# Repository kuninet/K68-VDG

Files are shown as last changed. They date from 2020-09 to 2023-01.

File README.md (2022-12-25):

# SBC6800/6809/6303用 VDGビデオボード

# ★★REV1.1 既知のバグ:  ☆☆
ガーバーデータに誤りがあり、2SC1815と2SC1015のシルク印刷が逆転しています。Q1、Q2の部品番号シルクが正しいです。

## 概要
- SBC68系バスにつながるMC6847 VDG LSIを使用したビデオボードです。
  - REV1基板はアドレスデコードラインにバグがあります。REV2で改善します。プリント基板をお使いの場合は、パターンカット、ジャンパが必要です

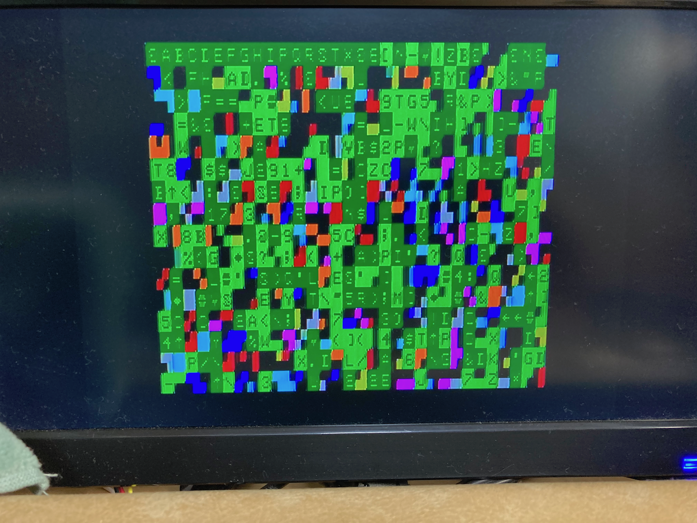
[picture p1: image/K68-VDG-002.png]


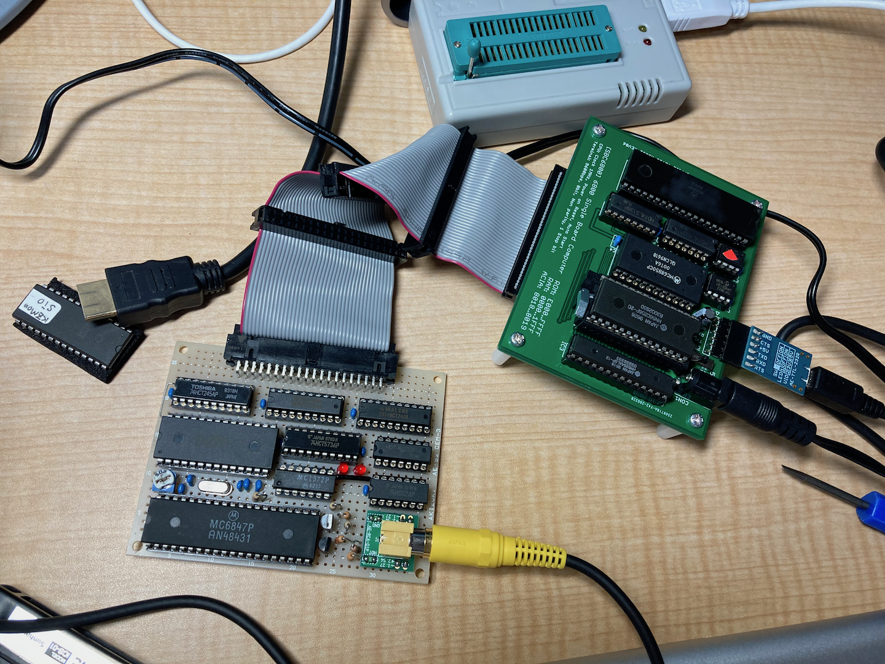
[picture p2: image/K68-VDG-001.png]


## メモリーマップ
- 本基板はVRAMとして8kBのメモリー領域と、VDG設定用レジスタがメモリーマップドI/Oとしてメモリーを占有します。
- 本基板はTomi9さん作のSBC I/O( https://sbc738827564.wordpress.com/2018/08/11/sbc-io-rev02/ )と共存できることを目指しています。

|メモリーアドレス|用途|
|:---|:---|
|$8110|VDG設定用レジスタ|
|\$A000-\$BFFF または \$C000-\$DFFF|ビデオRAM|

## SBC68系バス
- Tomi9さん作のSBC I/O ( https://sbc738827564.wordpress.com/2018/08/11/sbc-io-rev02/ ) に準拠しています。SBC6303ルーズキットとは若干信号線が異なりますのでご注意ください。(ジャンパを実施すれば使えます)

## ディレクトリ構造
|ディレクトリ|用途|
|:---|:---|
|KiCAD/|KiCAD用データ|
|image/|回路図等イメージデータ|

## ライセンス
- MITライセンスで公開します。

## Special Thanks
- 本基板は先人のみなさまの情報で作成することができました。
- pmig96さん・・・MC6847テストサーキット
  - https://pmig96.wordpress.com/2020/07/24/mc6847-test-circuit-part-3/
- Tomi9さん・・・SBC I/Oボード
  - https://sbc738827564.wordpress.com/2018/08/11/sbc-io-rev02/

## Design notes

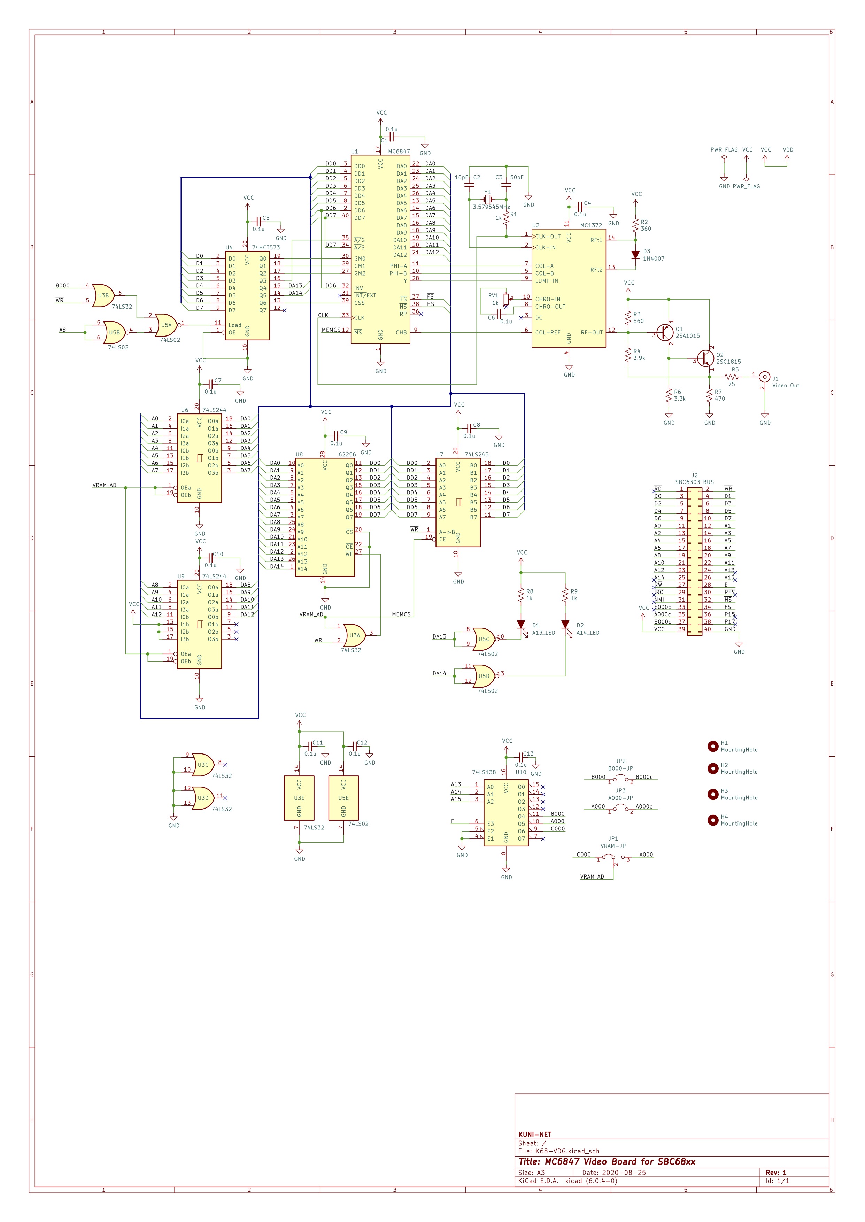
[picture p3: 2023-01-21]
image/K68-VDG.jpg

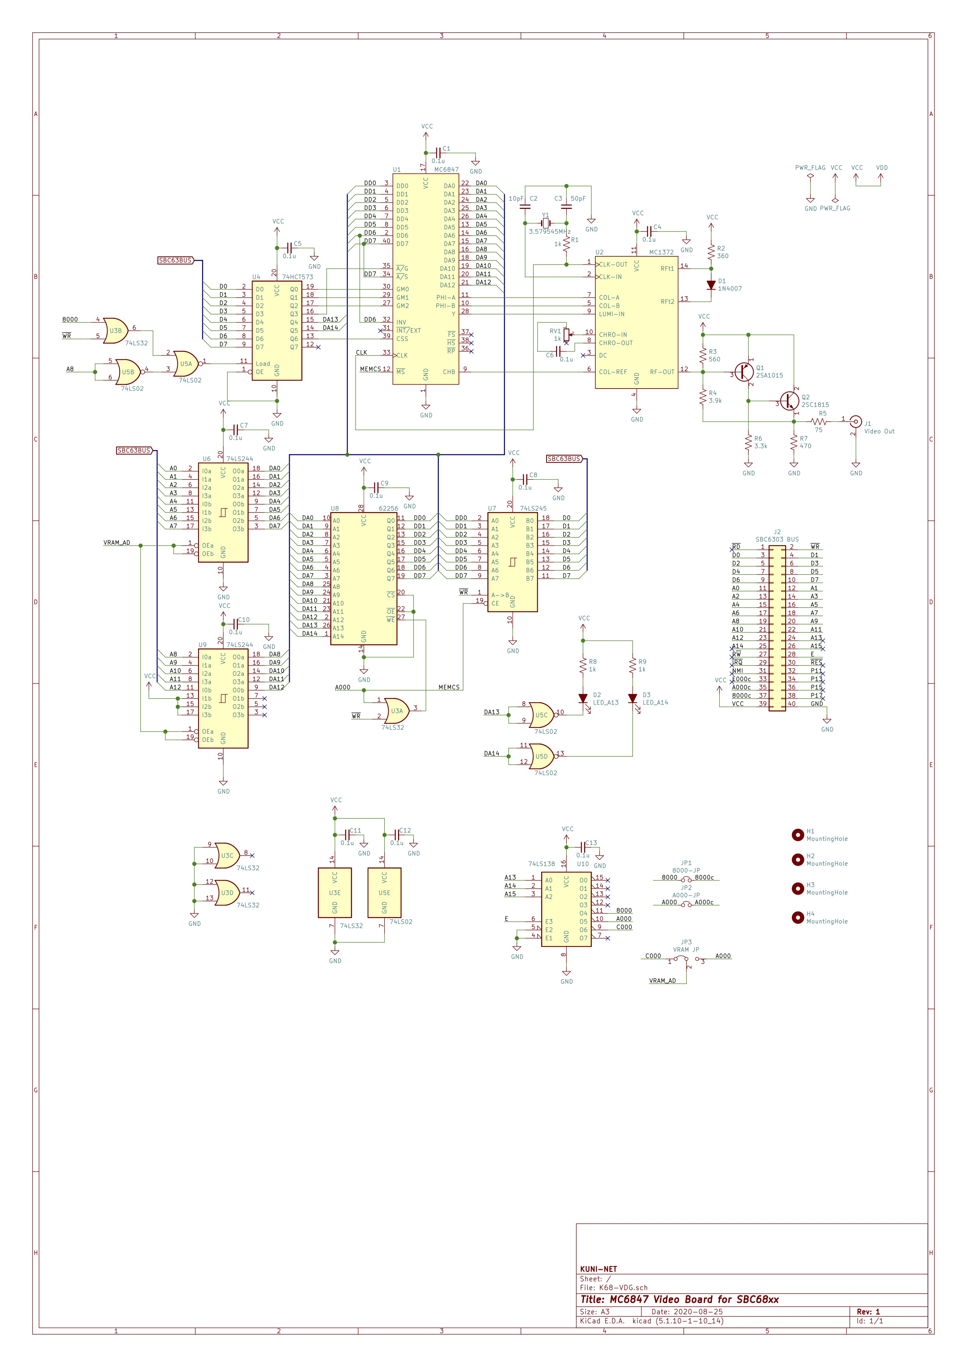
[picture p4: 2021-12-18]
image/K68-VDG-REV1.jpg

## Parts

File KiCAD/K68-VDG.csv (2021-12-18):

Reference | Value | Footprint | Datasheet
J2 | SBC6303 BUS | Connector_PinHeader_2.54mm:PinHeader_2x20_P2.54mm_Horizontal | ~
C1 | 0.1u | Capacitor_THT:C_Disc_D3.0mm_W1.6mm_P2.50mm | ~
C2 | 10pF | Capacitor_THT:C_Disc_D3.0mm_W1.6mm_P2.50mm | ~
C3 | 50pF | Capacitor_THT:C_Disc_D3.0mm_W1.6mm_P2.50mm | ~
C4 | 0.1u | Capacitor_THT:C_Disc_D3.0mm_W1.6mm_P2.50mm | ~
C5 | 0.1u | Capacitor_THT:C_Disc_D3.0mm_W1.6mm_P2.50mm | ~
C6 | 0.1u | Capacitor_THT:C_Disc_D3.0mm_W1.6mm_P2.50mm | ~
C7 | 0.1u | Capacitor_THT:C_Disc_D3.0mm_W1.6mm_P2.50mm | ~
C8 | 0.1u | Capacitor_THT:C_Disc_D3.0mm_W1.6mm_P2.50mm | ~
C9 | 0.1u | Capacitor_THT:C_Disc_D3.0mm_W1.6mm_P2.50mm | ~
C10 | 0.1u | Capacitor_THT:C_Disc_D3.0mm_W1.6mm_P2.50mm | ~
C11 | 0.1u | Capacitor_THT:C_Disc_D3.0mm_W1.6mm_P2.50mm | ~
C12 | 0.1u | Capacitor_THT:C_Disc_D3.0mm_W1.6mm_P2.50mm | ~
C13 | 0.1u | Capacitor_THT:C_Disc_D3.0mm_W1.6mm_P2.50mm | ~
D1 | 1N4007 | Diode_THT:D_DO-34_SOD68_P7.62mm_Horizontal | ~
D2 | LED_A13 | LED_THT:LED_D3.0mm | ~
D3 | LED_A14 | LED_THT:LED_D3.0mm | ~
H1 | MountingHole | MountingHole:MountingHole_3.2mm_M3 | ~
H2 | MountingHole | MountingHole:MountingHole_3.2mm_M3 | ~
H3 | MountingHole | MountingHole:MountingHole_3.2mm_M3 | ~
H4 | MountingHole | MountingHole:MountingHole_3.2mm_M3 | ~
J1 | Video Out | RCA:RCAConAE | ~
JP1 | 8000-JP | Jumper:SolderJumper-2_P1.3mm_Open_RoundedPad1.0x1.5mm | ~
JP2 | A000-JP | Jumper:SolderJumper-2_P1.3mm_Open_RoundedPad1.0x1.5mm | ~
Q1 | 2SA1015 | Package_TO_SOT_THT:TO-92_Inline | http://www.datasheetcatalog.org/datasheet/toshiba/905.pdf
Q2 | 2SC1815 | Package_TO_SOT_THT:TO-92_Inline | https://media.digikey.com/pdf/Data%20Sheets/Toshiba%20PDFs/2SC1815.pdf
R1 | 1k | Resistor_THT:R_Axial_DIN0207_L6.3mm_D2.5mm_P5.08mm_Vertical | ~
R2 | 360 | Resistor_THT:R_Axial_DIN0207_L6.3mm_D2.5mm_P10.16mm_Horizontal | ~
R3 | 560 | Resistor_THT:R_Axial_DIN0207_L6.3mm_D2.5mm_P10.16mm_Horizontal | ~
R4 | 3.9k | Resistor_THT:R_Axial_DIN0207_L6.3mm_D2.5mm_P10.16mm_Horizontal | ~
R5 | 75 | Resistor_THT:R_Axial_DIN0207_L6.3mm_D2.5mm_P10.16mm_Horizontal | ~
R6 | 3.3k | Resistor_THT:R_Axial_DIN0207_L6.3mm_D2.5mm_P10.16mm_Horizontal | ~
R7 | 470 | Resistor_THT:R_Axial_DIN0207_L6.3mm_D2.5mm_P10.16mm_Horizontal | ~
R8 | 1k | Resistor_THT:R_Axial_DIN0207_L6.3mm_D2.5mm_P10.16mm_Horizontal | ~
R9 | 1k | Resistor_THT:R_Axial_DIN0207_L6.3mm_D2.5mm_P10.16mm_Horizontal | ~
RV1 | 1k | Potentiometer_THT:Potentiometer_Bourns_3386P_Vertical | ~
U1 | MC6847 | Package_DIP:DIP-40_W15.24mm_Socket_LongPads
U10 | 74LS138 | Package_DIP:DIP-16_W7.62mm_Socket_LongPads | http://www.ti.com/lit/gpn/sn74LS138
U2 | MC1372 | Package_DIP:DIP-14_W7.62mm_Socket_LongPads
U3 | 74LS32 | Package_DIP:DIP-14_W7.62mm_Socket_LongPads | http://www.ti.com/lit/gpn/sn74LS32
U4 | 74HCT573 | Package_DIP:DIP-20_W7.62mm_Socket_LongPads | 74xx/74hc573.pdf
U5 | 74LS02 | Package_DIP:DIP-14_W7.62mm_Socket_LongPads | http://www.ti.com/lit/gpn/sn74hc02
U6 | 74LS244 | Package_DIP:DIP-20_W7.62mm_Socket_LongPads | http://www.ti.com/lit/gpn/sn74LS244
U7 | 74LS245 | Package_DIP:DIP-20_W7.62mm_Socket_LongPads | http://www.ti.com/lit/gpn/sn74LS245
U8 | 62256 | Package_DIP:DIP-28_W15.24mm_Socket_LongPads | https://ecee.colorado.edu/~mcclurel/Cypress_SRAM_CY62256.pdf
U9 | 74LS244 | Package_DIP:DIP-20_W7.62mm_Socket_LongPads | http://www.ti.com/lit/gpn/sn74LS244
Y1 | 3.579545MHz | Crystal:Crystal_HC49-U_Vertical | ~

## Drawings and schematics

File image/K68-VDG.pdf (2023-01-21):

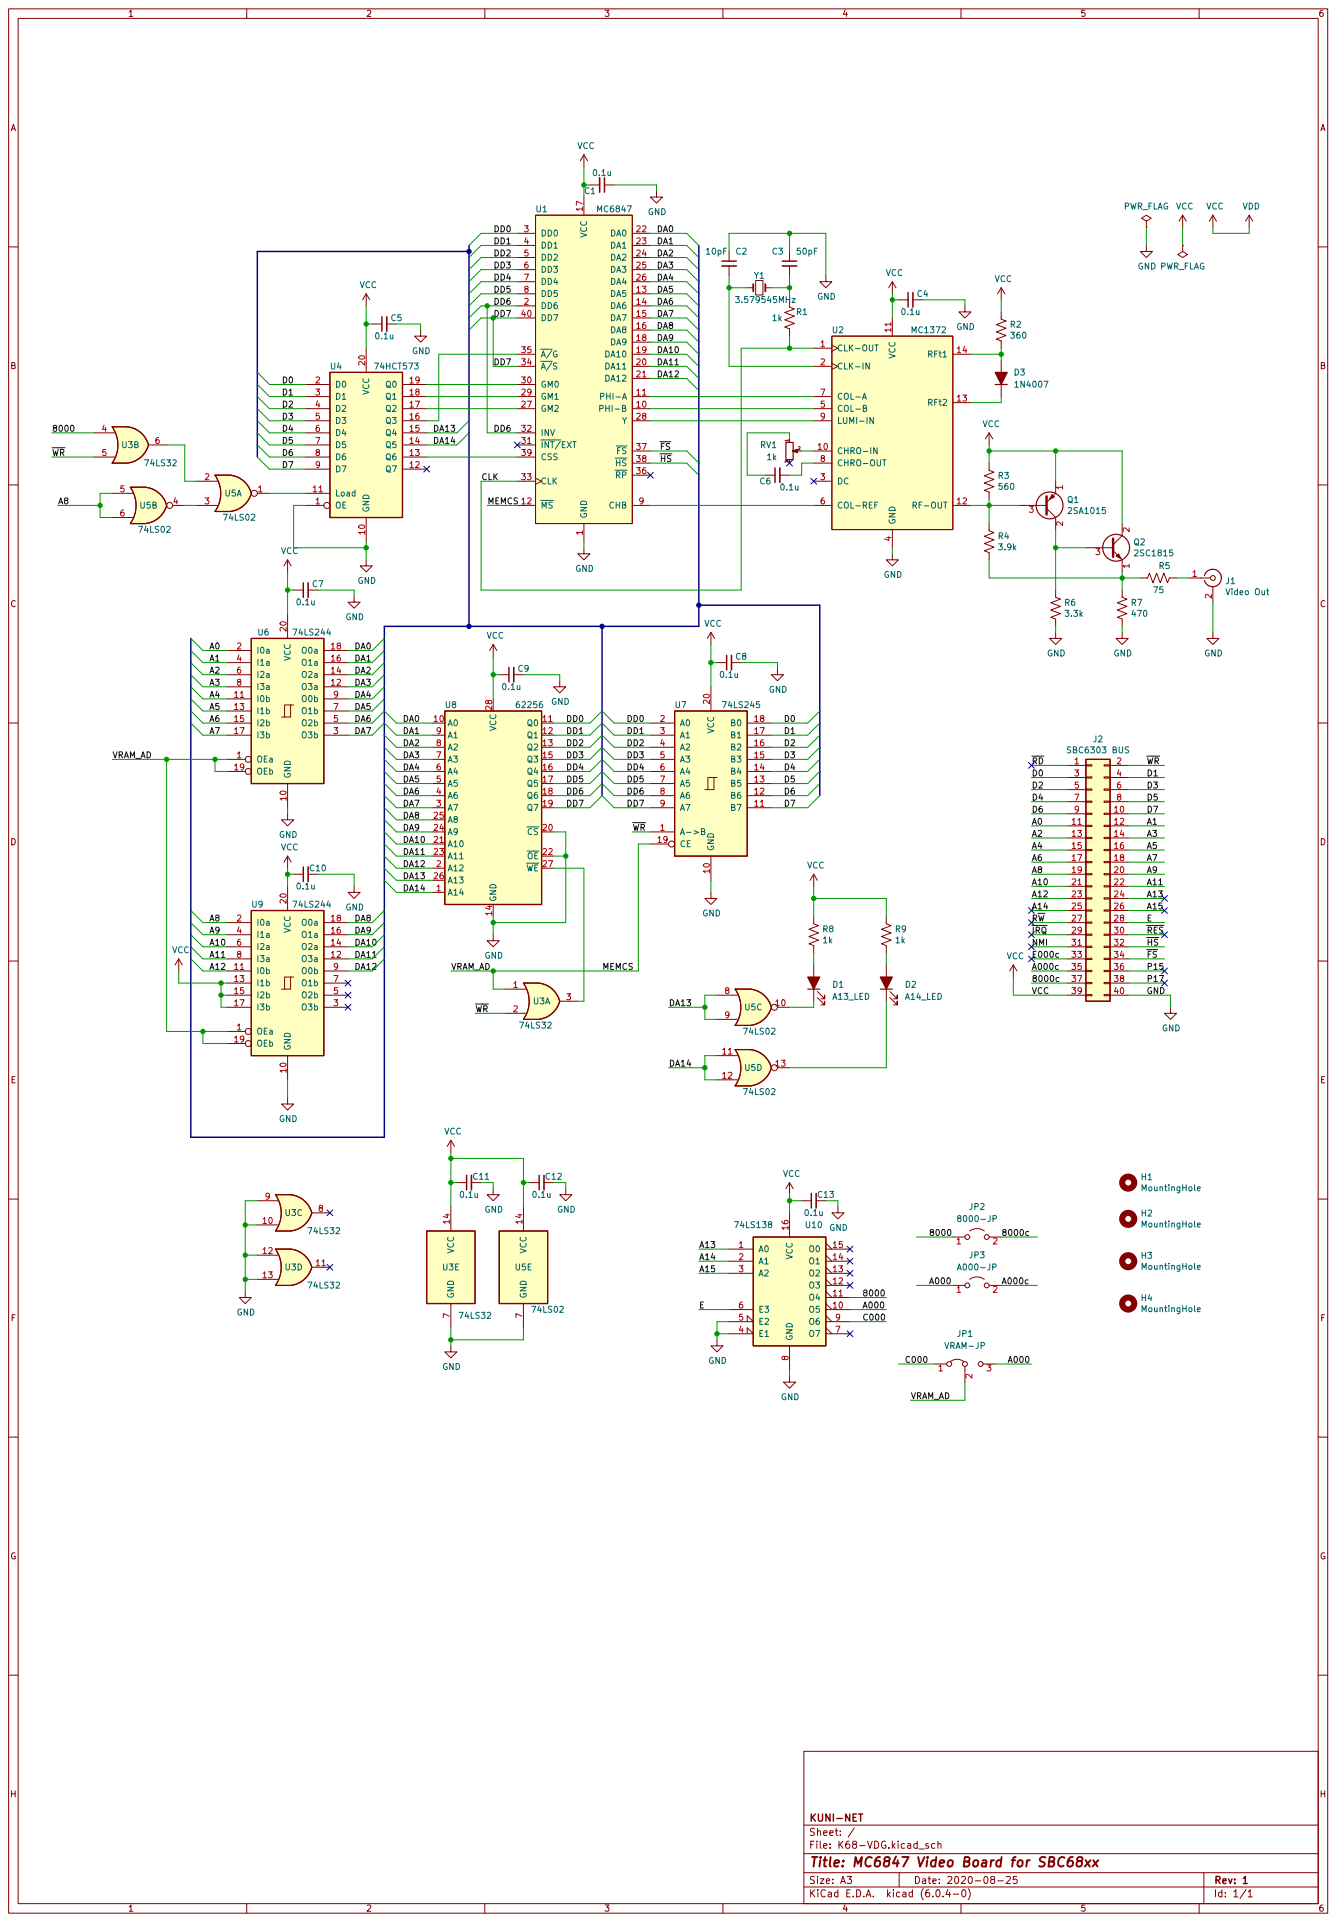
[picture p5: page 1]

1 PHI-B 10 PHI-A 11 ~{MS} 12 DA5 13 DA6 14 DA7 15 DA8 16 VCC 17 DA9 18 DA10 19 DD6 2 DA11 20 DA12 21 DA0 22 DA1 23 DA2 24 DA3 25 DA4 26 GM2 27 Y

4 COL-B 5 COL-REF 6 COL-A 7 CHRO-OUT 8

JP1 VRAM-JP D2 A14_LED GND GND

Id: 1/1 Title: MC6847 Video Board for SBC68xx File: K68-VDG.kicad_sch Sheet: / KUNI-NET

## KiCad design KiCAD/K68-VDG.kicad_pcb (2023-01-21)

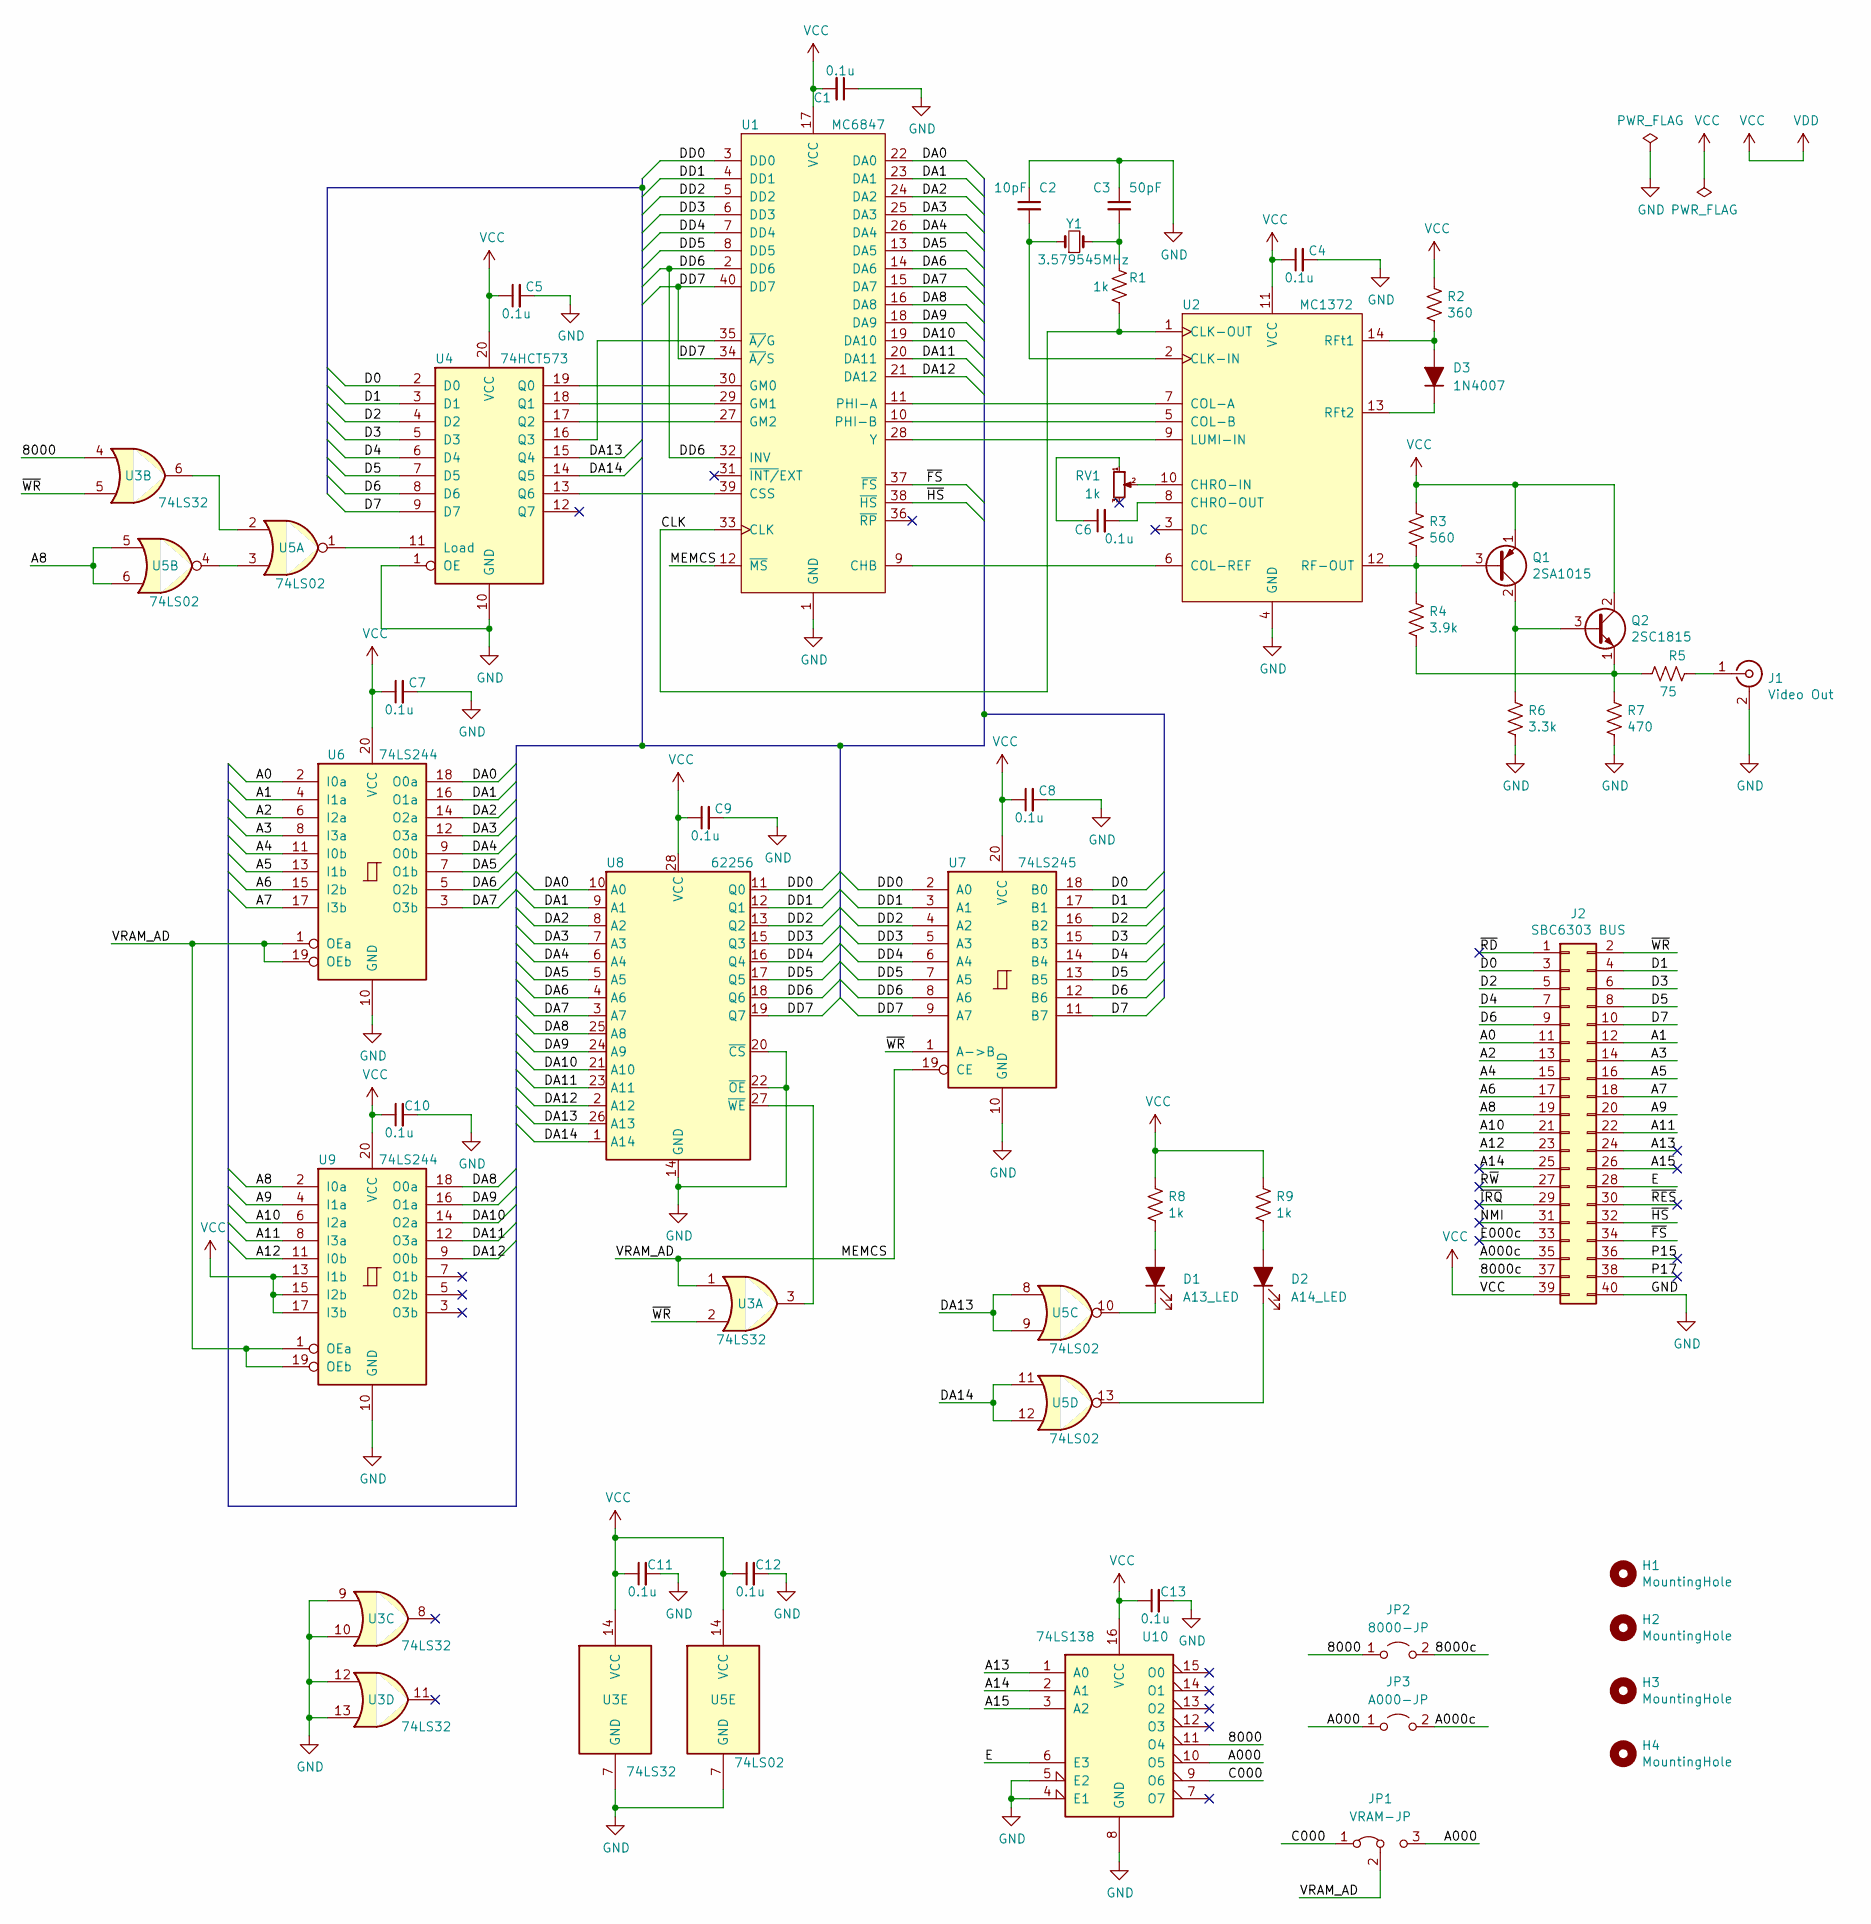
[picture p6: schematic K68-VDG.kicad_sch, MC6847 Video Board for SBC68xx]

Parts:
C1, C4, C5, C6, C7, C8, C9, C10, C11, C12, C13: 0.1u; C_Disc_D3.0mm_W1.6mm_P2.50mm
C2: 10pF; C_Disc_D3.0mm_W1.6mm_P2.50mm
C3: 50pF; C_Disc_D3.0mm_W1.6mm_P2.50mm
D1: A13_LED; LED_D3.0mm
D2: A14_LED; LED_D3.0mm
D3: 1N4007; D_DO-34_SOD68_P10.16mm_Horizontal
H1, H2, H3, H4: MountingHole; MountingHole_3.2mm_M3
J1: Video Out; RCAConAE
J2: SBC6303 BUS; PinHeader_2x20_P2.54mm_Horizontal
JP1: VRAM-JP; SolderJumper-3_P1.3mm_Bridged12_RoundedPad1.0x1.5mm
JP2: 8000-JP; SolderJumper-2_P1.3mm_Open_RoundedPad1.0x1.5mm
JP3: A000-JP; SolderJumper-2_P1.3mm_Open_RoundedPad1.0x1.5mm
Q1: 2SA1015; TO-92_Inline_Wide
Q2: 2SC1815; TO-92_Inline_Wide
R1: 1k; R_Axial_DIN0207_L6.3mm_D2.5mm_P5.08mm_Vertical
R2: 360; R_Axial_DIN0207_L6.3mm_D2.5mm_P10.16mm_Horizontal
R3: 560; R_Axial_DIN0207_L6.3mm_D2.5mm_P10.16mm_Horizontal
R4: 3.9k; R_Axial_DIN0207_L6.3mm_D2.5mm_P10.16mm_Horizontal
R5: 75; R_Axial_DIN0207_L6.3mm_D2.5mm_P10.16mm_Horizontal
R6: 3.3k; R_Axial_DIN0207_L6.3mm_D2.5mm_P10.16mm_Horizontal
R7: 470; R_Axial_DIN0207_L6.3mm_D2.5mm_P10.16mm_Horizontal
R8, R9: 1k; R_Axial_DIN0207_L6.3mm_D2.5mm_P10.16mm_Horizontal
RV1: 1k; Potentiometer_Vishay_T73YP_Vertical
U1: MC6847; DIP-40_W15.24mm_Socket_LongPads
U2: MC1372; DIP-14_W7.62mm_Socket_LongPads
U3: 74LS32; DIP-14_W7.62mm_Socket_LongPads
U4: 74HCT573; DIP-20_W7.62mm_Socket_LongPads
U5: 74LS02; DIP-14_W7.62mm_Socket_LongPads
U6, U9: 74LS244; DIP-20_W7.62mm_Socket_LongPads
U7: 74LS245; DIP-20_W7.62mm_Socket_LongPads
U8: 62256; DIP-28_W15.24mm_Socket_LongPads
U10: 74LS138; DIP-16_W7.62mm_Socket_LongPads
Y1: 3.579545MHz; Crystal_HC49-U_Vertical

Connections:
/8000: JP2.1 (A), U3.4, U10.11 (O4)
/8000c: J2.37, JP2.2 (B)
/A0: J2.11, U6.2 (I0a)
/A000: JP1.3 (B), JP3.1 (A), U10.10 (O5)
/A000c: J2.35, JP3.2 (B)
/A1: J2.12, U6.4 (I1a)
/A2: J2.13, U6.6 (I2a)
/A3: J2.14, U6.8 (I3a)
/A4: J2.15, U6.11 (I0b)
/A5: J2.16, U6.13 (I1b)
/A6: J2.17, U6.15 (I2b)
/A7: J2.18, U6.17 (I3b)
/A8: J2.19, U5.5, U5.6, U9.2 (I0a)
/A9: J2.20, U9.4 (I1a)
/A10: J2.21, U9.6 (I2a)
/A11: J2.22, U9.8 (I3a)
/A12: J2.23, U9.11 (I0b)
/A13: J2.24, U10.1 (A0)
/A14: J2.25, U10.2 (A1)
/A15: J2.26, U10.3 (A2)
/C000: JP1.1 (A), U10.9 (O6)
/CLK: R1.2, U1.33 (CLK), U2.1 (CLK-OUT)
/D0: J2.3, U4.2 (D0), U7.18 (B0)
/D1: J2.4, U4.3 (D1), U7.17 (B1)
/D2: J2.5, U4.4 (D2), U7.16 (B2)
/D3: J2.6, U4.5 (D3), U7.15 (B3)
/D4: J2.7, U4.6 (D4), U7.14 (B4)
/D5: J2.8, U4.7 (D5), U7.13 (B5)
/D6: J2.9, U4.8 (D6), U7.12 (B6)
/D7: J2.10, U4.9 (D7), U7.11 (B7)
/DA0: U1.22 (DA0), U6.18 (O0a), U8.10 (A0)
/DA1: U1.23 (DA1), U6.16 (O1a), U8.9 (A1)
/DA2: U1.24 (DA2), U6.14 (O2a), U8.8 (A2)
/DA3: U1.25 (DA3), U6.12 (O3a), U8.7 (A3)
/DA4: U1.26 (DA4), U6.9 (O0b), U8.6 (A4)
/DA5: U1.13 (DA5), U6.7 (O1b), U8.5 (A5)
/DA6: U1.14 (DA6), U6.5 (O2b), U8.4 (A6)
/DA7: U1.15 (DA7), U6.3 (O3b), U8.3 (A7)
/DA8: U1.16 (DA8), U8.25 (A8), U9.18 (O0a)
/DA9: U1.18 (DA9), U8.24 (A9), U9.16 (O1a)
/DA10: U1.19 (DA10), U8.21 (A10), U9.14 (O2a)
/DA11: U1.20 (DA11), U8.23 (A11), U9.12 (O3a)
/DA12: U1.21 (DA12), U8.2 (A12), U9.9 (O0b)
/DA13: U4.15 (Q4), U5.8, U5.9, U8.26 (A13)
/DA14: U4.14 (Q5), U5.11, U5.12, U8.1 (A14)
/DD0: U1.3 (DD0), U7.2 (A0), U8.11 (Q0)
/DD1: U1.4 (DD1), U7.3 (A1), U8.12 (Q1)
/DD2: U1.5 (DD2), U7.4 (A2), U8.13 (Q2)
/DD3: U1.6 (DD3), U7.5 (A3), U8.15 (Q3)
/DD4: U1.7 (DD4), U7.6 (A4), U8.16 (Q4)
/DD5: U1.8 (DD5), U7.7 (A5), U8.17 (Q5)
/DD6: U1.2 (DD6), U1.32 (INV), U7.8 (A6), U8.18 (Q6)
/DD7: U1.34 (~A/S), U1.40 (DD7), U7.9 (A7), U8.19 (Q7)
/E: J2.28, U10.6 (E3)
/E000c: J2.33
/MEMCS: JP1.2 (C), U1.12 (~MS), U3.1, U6.1 (OEa), U6.19 (OEb), U7.19 (CE), U9.1 (OEa), U9.19 (OEb)
/NMI: J2.31
/P15: J2.36
/P17: J2.38
/R~W: J2.27
/~FS: J2.34, U1.37 (~FS)
/~HS: J2.32, U1.38 (~HS)
/~IRQ: J2.29
/~RD: J2.1
/~RES: J2.30
/~WR: J2.2, U3.2, U3.5, U7.1 (A->B)
unnamed: C2.2, U2.2 (CLK-IN), Y1.1
unnamed: C3.2, R1.1, Y1.2
unnamed: C6.1, RV1.1
unnamed: C6.2, U2.8 (CHRO-OUT)
unnamed: J1.1 (In), R5.1
unnamed: Q1.2 (C), Q2.3 (B), R6.1
unnamed: Q1.3 (B), R3.2, R4.1, U2.12 (RF-OUT)
unnamed: Q2.1 (E), R4.2, R5.2, R7.1
unnamed: D3.2 (A), R2.2, U2.14 (RFt1)
unnamed: D1.2 (A), R8.2
unnamed: D2.2 (A), R9.2
unnamed: U1.9 (CHB), U2.6 (COL-REF)
unnamed: U1.10 (PHI-B), U2.5 (COL-B)
unnamed: U1.11 (PHI-A), U2.7 (COL-A)
unnamed: U1.27 (GM2), U4.17 (Q2)
unnamed: U1.28 (Y), U2.9 (LUMI-IN)
unnamed: U1.29 (GM1), U4.18 (Q1)
unnamed: U1.30 (GM0), U4.19 (Q0)
unnamed: U1.35 (~A/G), U4.16 (Q3)
unnamed: U1.39 (CSS), U4.13 (Q6)
unnamed: RV1.2, U2.10 (CHRO-IN)
unnamed: D3.1 (K), U2.13 (RFt2)
unnamed: U3.3, U8.27 (~WE)
unnamed: U3.6, U5.2
unnamed: U4.11 (Load), U5.1
unnamed: U5.3, U5.4
unnamed: D1.1 (K), U5.10
unnamed: D2.1 (K), U5.13

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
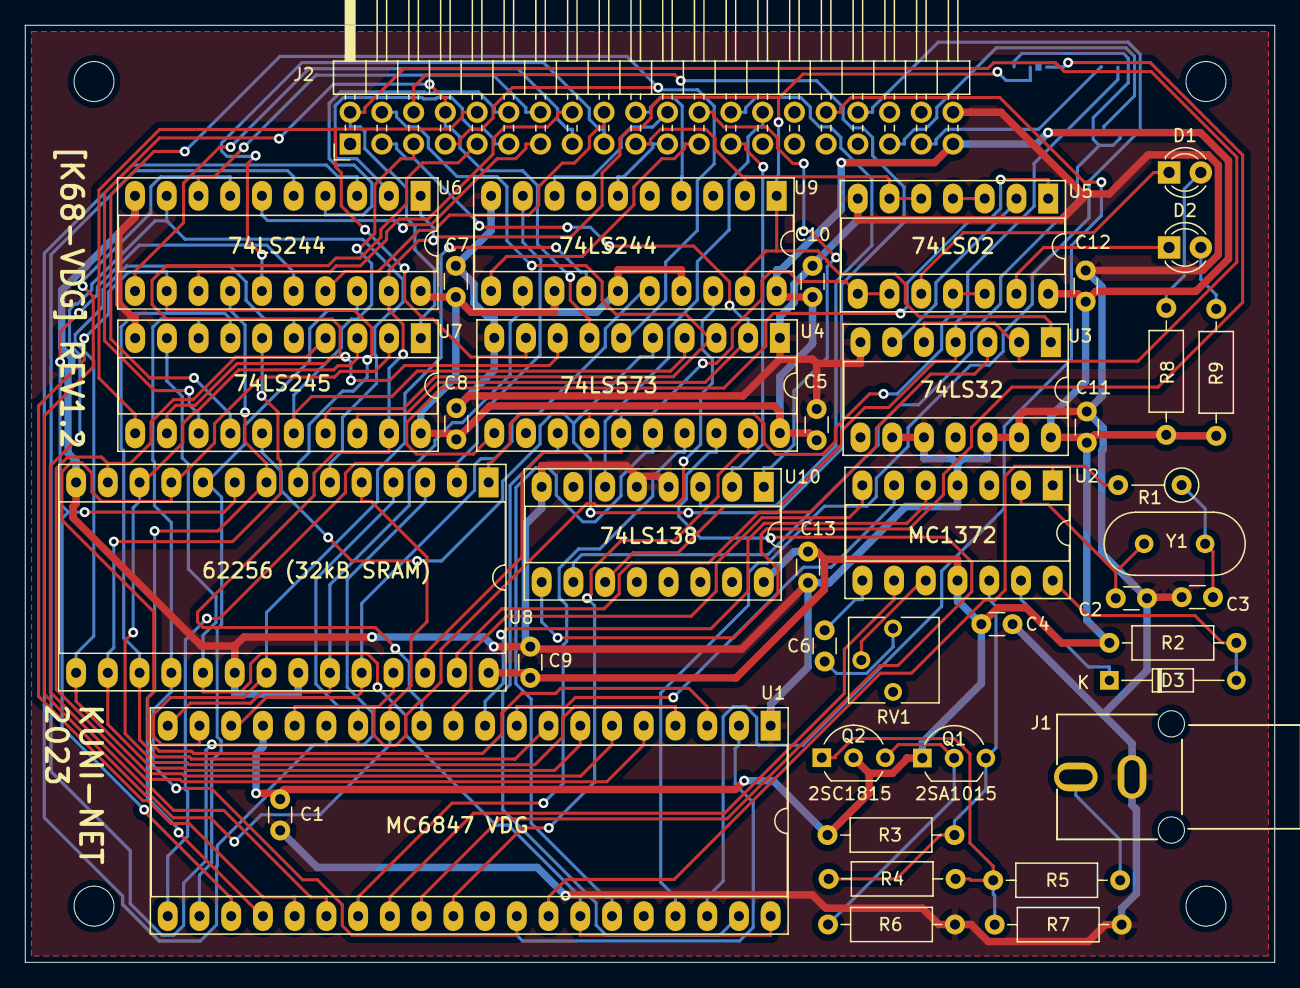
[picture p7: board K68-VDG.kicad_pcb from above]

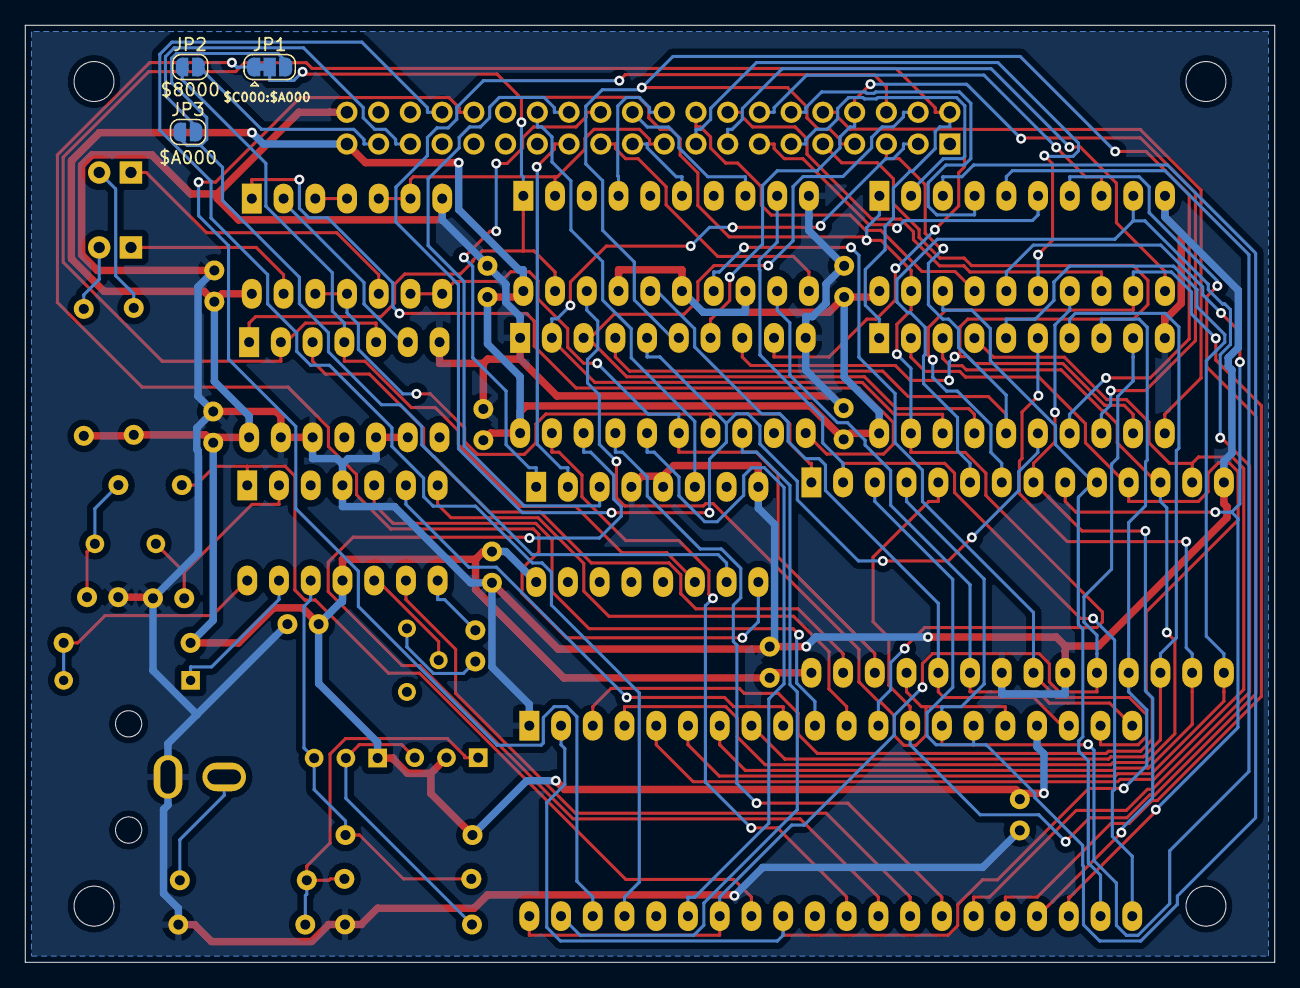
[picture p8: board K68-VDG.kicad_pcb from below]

Board: 2 copper layers, 100.0 x 75.0 mm, 48 parts (3 on the bottom side), 88 nets.

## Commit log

2020-09-05 init commit
    [K68-VDG.kicad_pcb, K68-VDG.sch]
2020-09-05 回路図等画像追加
2020-09-05 ASCIIキャラクタ一覧表示デモプログラム作成
2020-09-05 ソースコメント追加
2020-09-05 エコーバックテストプログラム追加
2020-09-07 エコーバックプログラム改良
2021-12-18 回路修正、REV1基板ガーバーデータ出力
    [K68-VDG.GBL, K68-VDG.GBO, K68-VDG.GBP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]
2021-12-18 回路図イメージ更新
2022-11-04 REV1.1 バグ修正板 ガーバー出力
    [K68-VDG.GBL, K68-VDG.GBO, K68-VDG.GBP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]
2023-01-21 .DS_Storeを削除
2023-01-21 基板シルク印刷間違い訂正、回路図C1間違い訂正、v1.2ガーバー出力
    [K68-VDG.GBL, K68-VDG.GBO, K68-VDG.GBP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]
2025-03-09 Itty Bitty Computers 2k BASIC用ドライバ更新(未完成)
2025-03-20 echoback サンプル バックスペース対応
2025-03-20 BS処理の場所変更 & VTAM TOP判定
2025-03-20 エコーバックプログラム コメント追加
